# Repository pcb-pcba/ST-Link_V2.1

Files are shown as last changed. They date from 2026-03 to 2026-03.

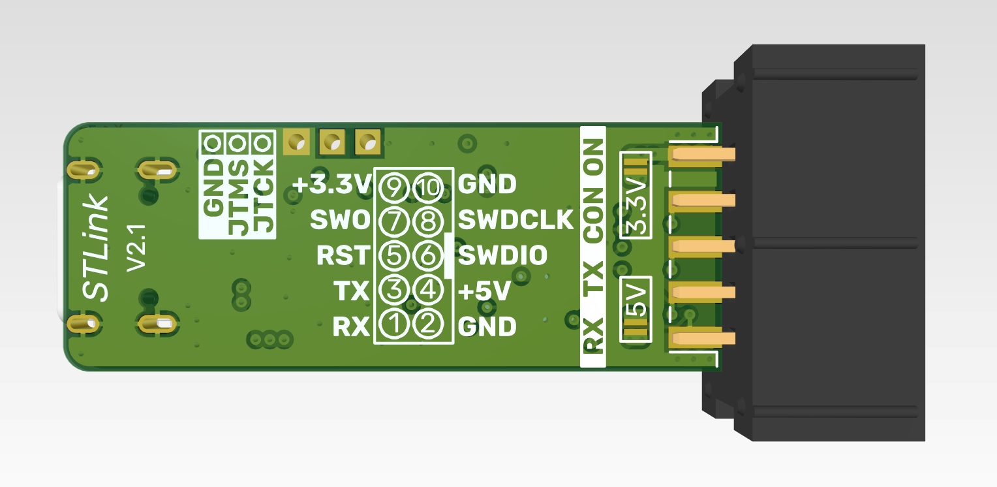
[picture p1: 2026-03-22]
Project/2.jpg

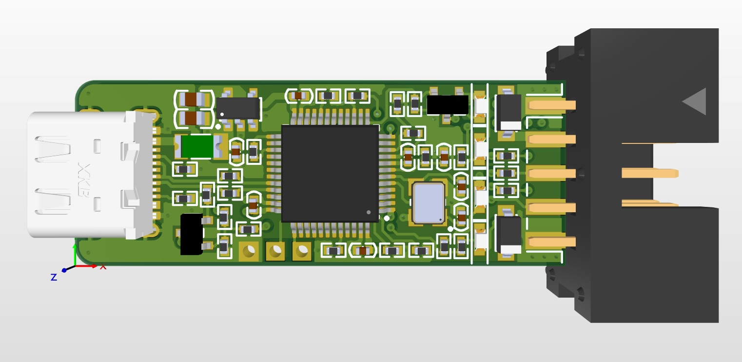
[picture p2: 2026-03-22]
Project/1.jpg

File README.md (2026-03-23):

# ST-Link V2.1

<p align="center">
  
</p>
<p align="center">
  
</p>

Small version of ST-Link v2.1 (37mm x 14mm board)<br><br>
**Features**
  - SWD (Serial Wire Debug) - standard pins used for external targets include SWDIO, SWCLK, GND, and sometimes NRST.
  - Virtual COM Port (VCP)
  - USB Power Management: Supports requesting more than 100 mA from the host PC to power the application board.
  - SWO Support: Includes a Serial Wire Output (SWO) pin for real-time trace debugging, which is often missing on common "dongle" clones of the V2.

`Draftsman_STLinkV2_1_rev1_0.pdf` - Some useful drawings

`Schematic_STLinkV2_1_rev1_0.pdf` - Schematic

`Project/` - Project files

`Gerber/STLinkV2_1_rev1_0.zip` - Gerber files

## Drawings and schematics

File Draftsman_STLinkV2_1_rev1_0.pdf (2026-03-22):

# ST-Link V2.1 V. 1.0

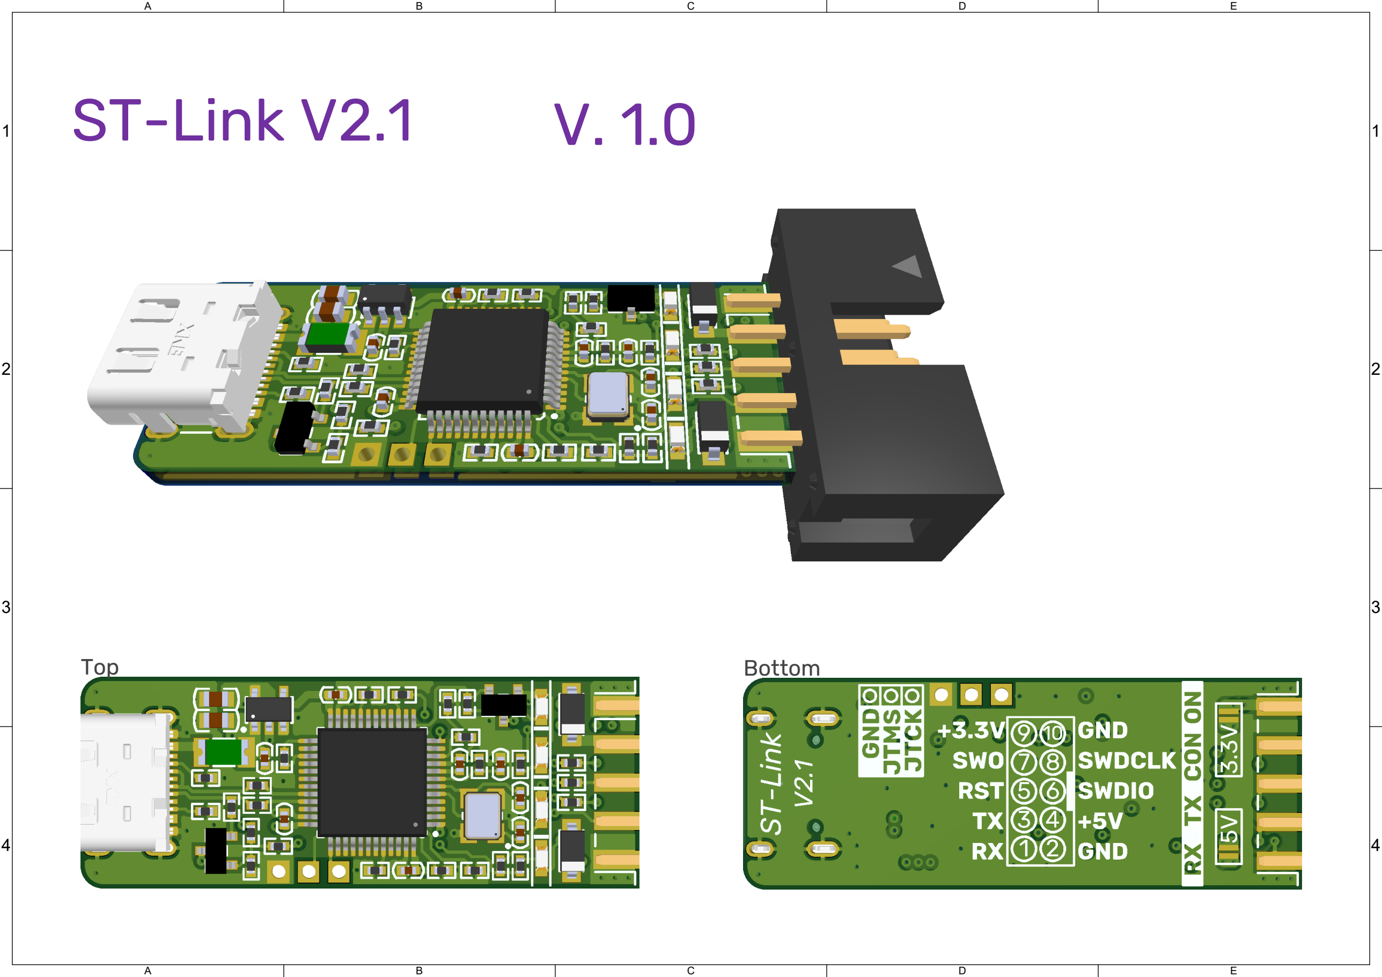
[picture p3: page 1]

A

B

C

D

E

1 | 1
2 | 2
3 | 3
4 | 4
Top | Bottom

## F1Q²

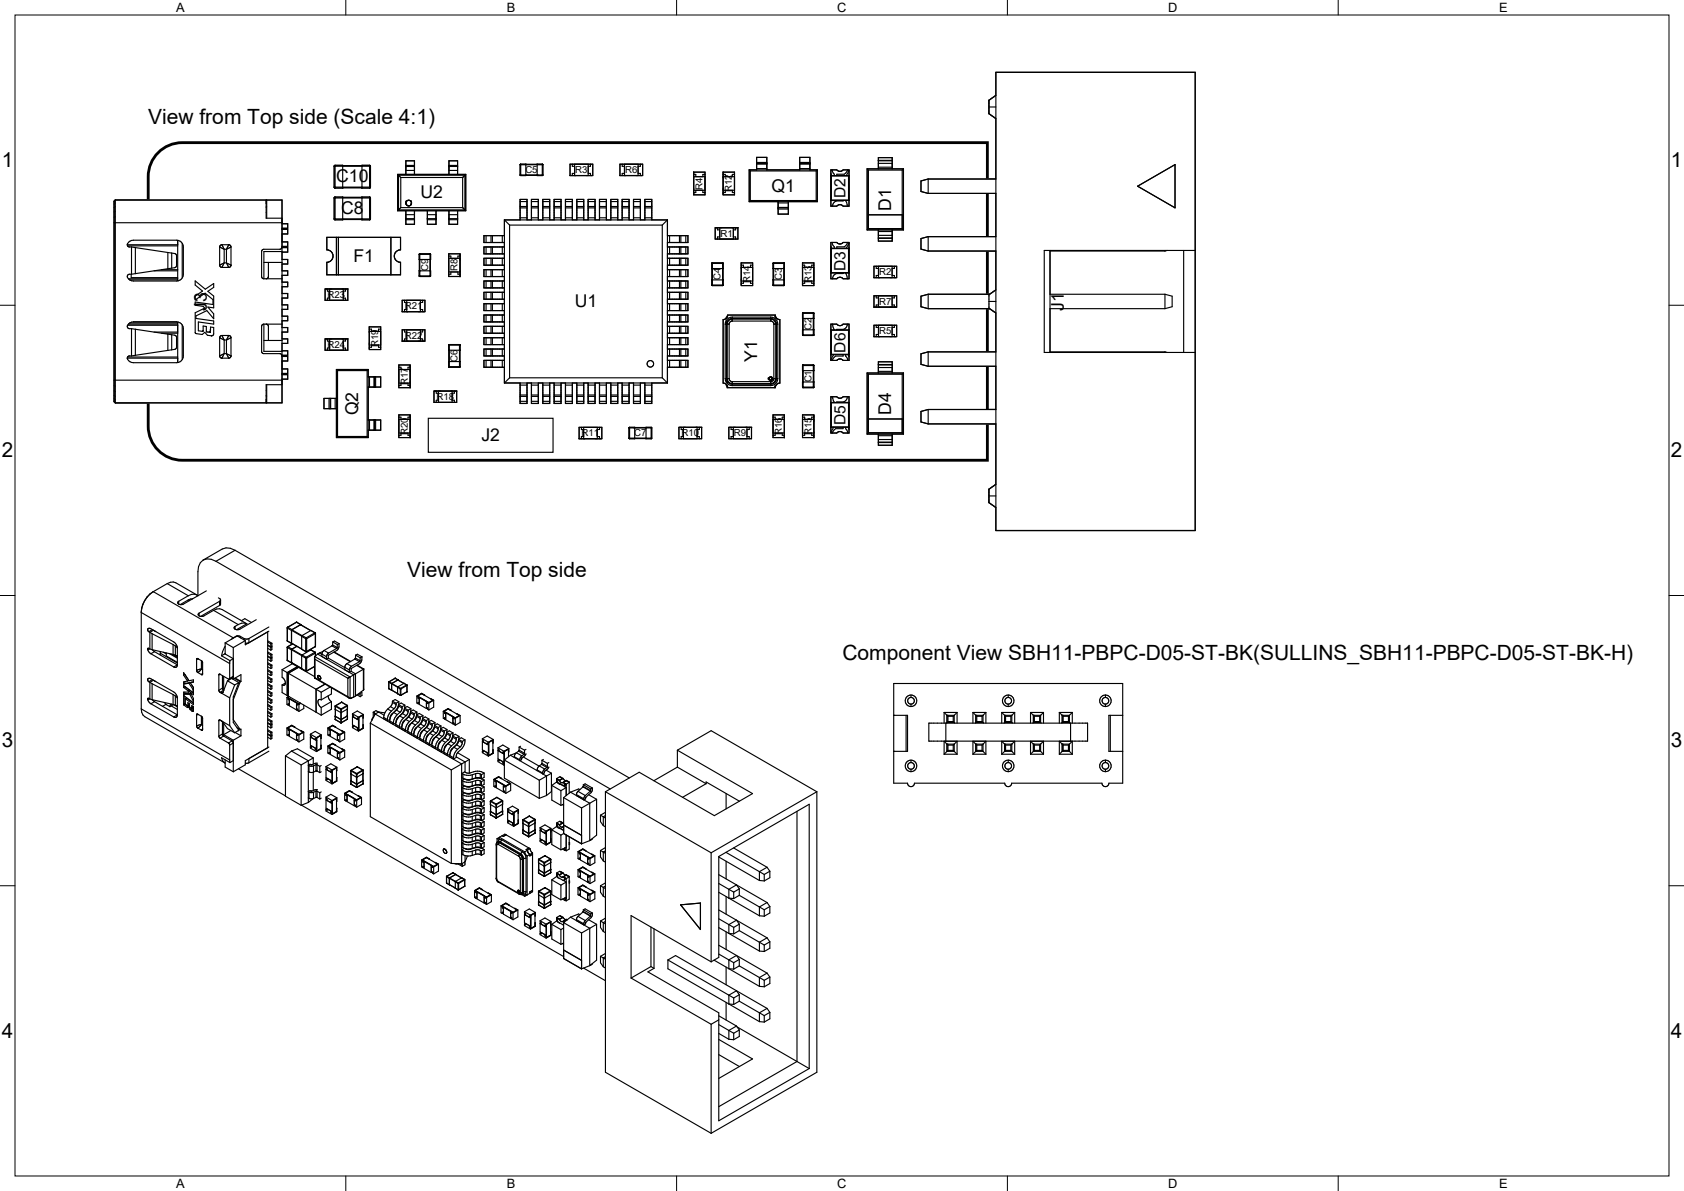
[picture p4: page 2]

View from Top side (Scale 4:1)

View from Top side

Component View SBH11-PBPC-D05-ST-BK(SULLINS_SBH11-PBPC-D05-ST-BK-H)

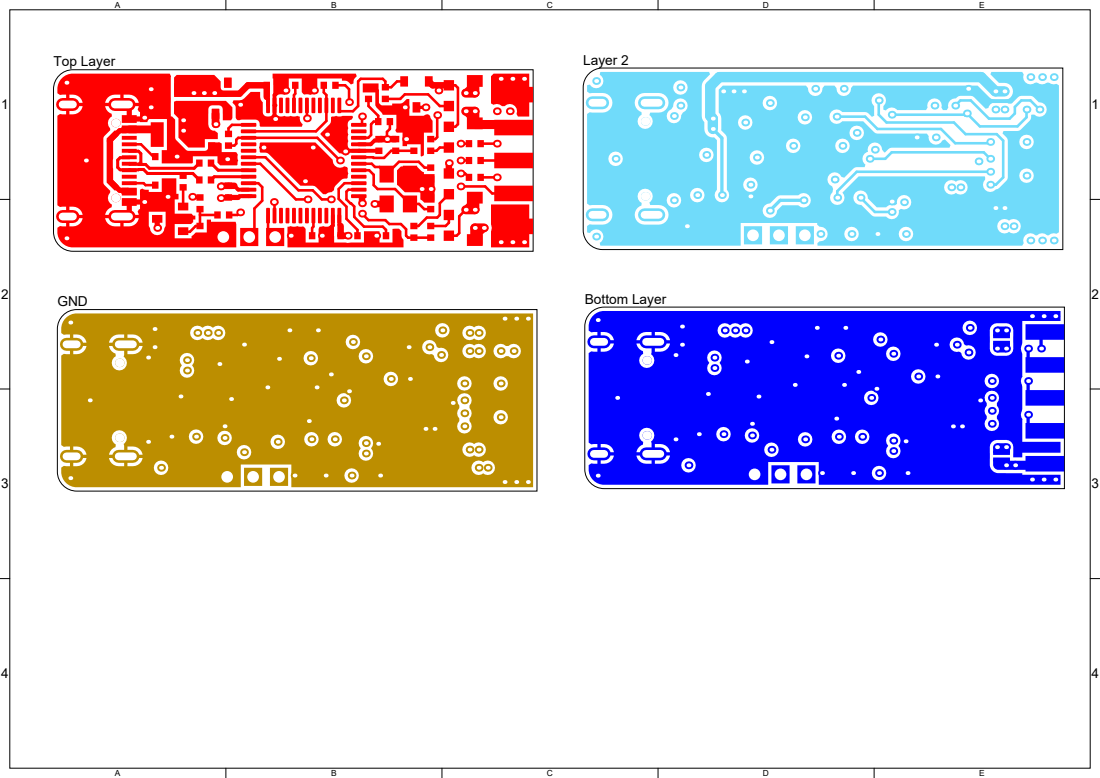
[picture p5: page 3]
Top Layer; GND; Layer 2; Bottom Layer

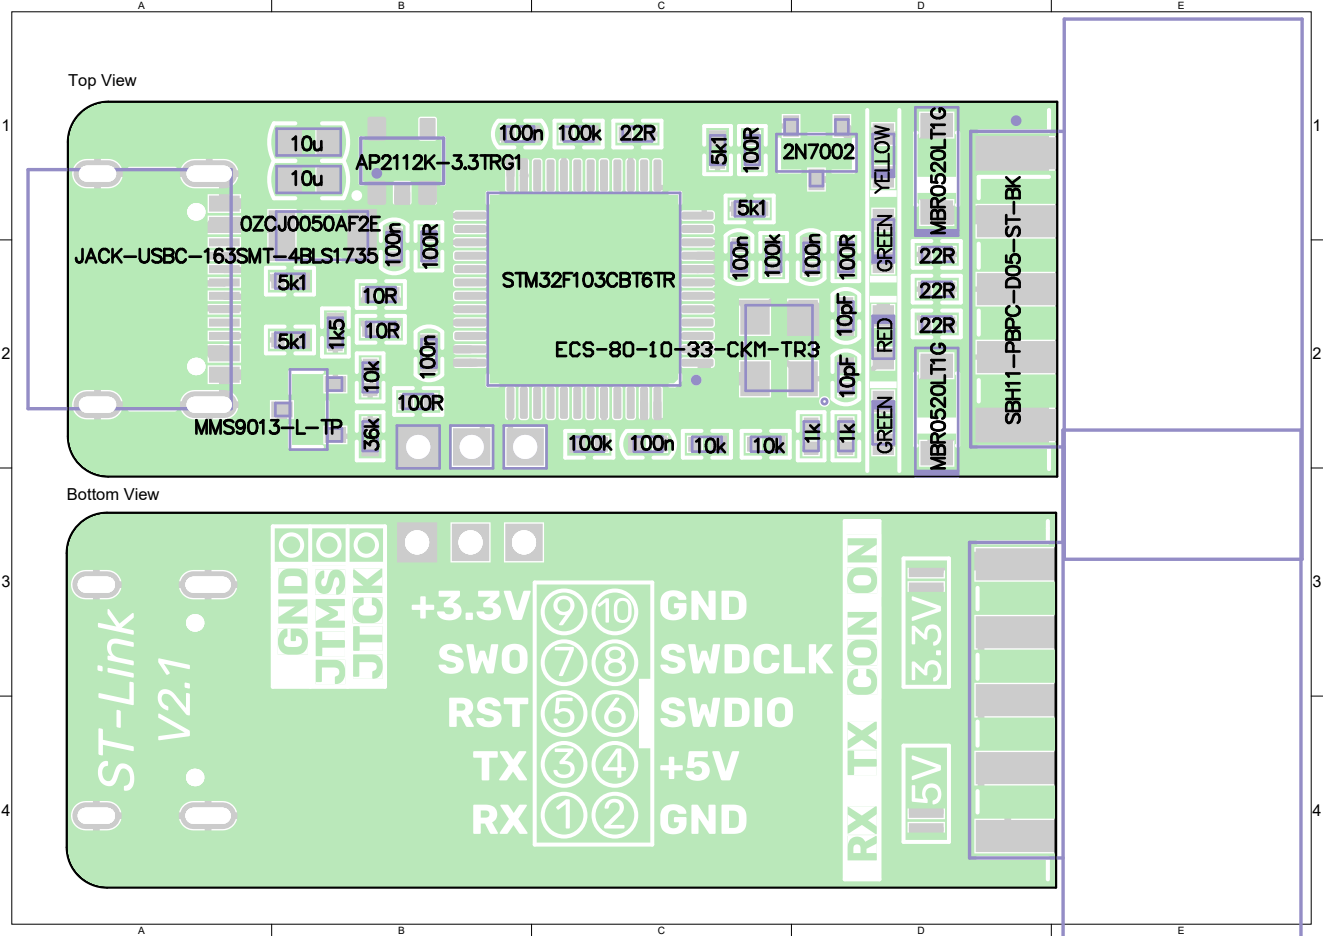
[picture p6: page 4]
Top View; Bottom View

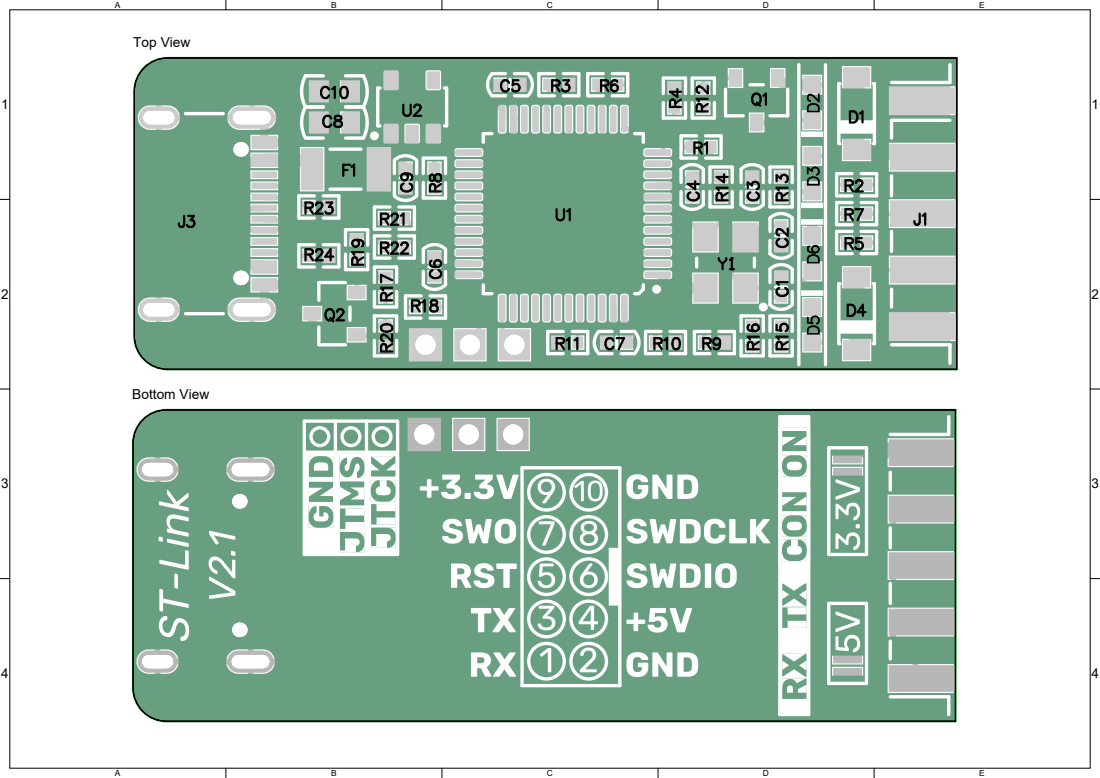
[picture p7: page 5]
Top View; Bottom View

1 | 1
2 | 2
3 | 3
4 | 4
Material | Layer | Thickness Dielectric Material Type | Gerber
| Top Overlay | | Legend | GTO
Surface Material Top Solder | 0.01mm | Solder Resist | Solder Mask GTS
Copper | Top Layer | 0.04mm | Signal | GTL
Prepreg | 0.21mm | PP-006 | Dielectric
CF-004 | GND | 0.02mm | Signal | G1
1.06mm | FR-4 | Dielectric
CF-004 | Layer 2 | 0.02mm | Signal | G2
Prepreg | 0.21mm | PP-006 | Dielectric
Copper | Bottom Layer | 0.04mm | Signal | GBL
Surface Material Bottom Solder 0.01mm | Solder Resist | Solder Mask GBS
| Bottom Overlay | | Legend | GBO
Total thickness: 1.61mm

Layer Stack Legend

1 | 1
2 | 2
3 | 3
4 | 4
Line # | Designator | Comment | Quantity | Manufacturer Part Number 1 | Case/Package | Description
1 | C1, C2 | 10pF | 2 | GCM1555C1H100JA16D | 0402 | 50V 10pF C0G ±5% 0402 Multilayer Ceramic Capacitors MLCC - SMD/SMT ROHS
2 | C3, C4, C5, C6, C7, C9 | 100n | 6 | GCM155R71H104KE02D | 0402 | 50V 100nF X7R ±10% 0402 Multilayer Ceramic Capacitors MLCC - SMD/SMT ROHS
3 | C8, C10 | 10u | 2 | GRM188C81C106MA73D | 0603 | 10 µF ±20% 16V Ceramic Capacitor X6S 0603 (1608 Metric)
4 | D1, D4 | MBR0520LT1G | 2 | MBR0520LT1G | SOD-123-2 | Diode, Schottky Barrier, Vr 20V, If 0.5A, Pkg SOD-123, Vf 0.385V, Tj +125DEGC, Cs 5.5A
5 | D2 | YELLOW | 1 | 150060YS75003 | | Led, Yellow, 550Mcd, 595Nm Rohs Compliant: Yes
6 | D3, D5 | GREEN | 2 | 150060VS75003 | | Led, Bright Green, 100Mcd, 572Nm Rohs Compliant: Yes
7 | D6 | RED | 1 | 150060RS75003 | 0603 | SMT Mono-Color Chip LED Waterclear Advance WL-SMCW_0603_ADVANCE
8 | F1 | 0ZCJ0050AF2E | 1 | 0ZCJ0050AF2E | 1206 | Resettable Fuse, PPTC, 1206 (3216 Metric), 0ZCJ Series, 24 VDC, 500 mA, 1 A, 0.1 s
9 | J1 | SBH11-PBPC-D05-ST-BK | 1 | SBH11-PBPC-D05-ST-BK | | Conn Shrouded Header (4 Sides) HDR 10 POS 2.54mm Solder ST Top Entry Thru-Hole
10 | J3 | JACK-USBC-163SMT-4BLS1735 | 1 | JACK-USBC-163SMT-4BLS1735 | | Usb Type C Jack IPX7 SMT
11 | Q1 | 2N7002 | 1 | 2N7002H6327XTSA2 | SOT-23 | MOSFET N-CH 60V 300MA SOT23-3 N-Channel 60 V 300mA (Ta) 500mW (Ta) Surface Mount PG-SOT23
12 | Q2 | MMS9013-L-TP | 1 | MMS9013-L-TP | SOT-23 | Small Signal Bipolar Transistor, 0.5A I(C), 25V V(BR)CEO, 1-Element, NPN, Silicon
13 | R1, R4, R23, R24 | 5k1 | 4 | AC0402FR-135K1L | 0402 | Res Thick Film 0402 5.1K Ohm 1% 0.063W(1/16W) ±100ppm/°C Pad SMD T/R Automotive AEC-Q200
14 | R2, R5, R6, R7 | 22R | 4 | AC0402FR-7W22RL | 0402 | 125mW Thick Film Resistors ±100ppm/℃ ±1% 22Ω 0402 Chip Resistor - Surface Mount ROHS
15 | R3, R11, R14 | 100k | 3 | AC0402FR-7W100KL | 0402 | Res Thick Film 0402 100K Ohm 1% 0.125W(1/8W) ±100ppm/°C Pad SMD T/R Automotive AEC-Q200
16 | R8, R12, R13, R18 | 100R | 4 | AC0402FR-7W100RL | 0402 | Res Thick Film 0402 100 Ohm 1% 0.125W(1/8W) ±100ppm/ C Pad SMD T/R Automotive AEC-Q200
17 | R9, R10, R17 | 10k | 3 | AC0402FR-7W10KL | 0402 | Res Thick Film 0402 10K Ohm 1% 0.125W(1/8W) ±100ppm/ C Pad SMD Automotive T/R
18 | R15, R16 | 1k | 2 | AC0402FR-7W1KL | 0402 | Res Thick Film 0402 1K Ohm 1% 0.125W(1/8W) ±100ppm/C Pad SMD Automotive T/R
19 | R19 | 1k5 | 1 | AC0402FR-7W1K5L | 0402 | Fixed Resistor, Metal Glaze/thick Film, 0.125W, 1500ohm, 75V, 1% +/-Tol, 100ppm/Cel, Surface Mount, 0402
20 | R20 | 36k | 1 | AC0402FR-7W36KL | 0402 | Chip Resistor Automotive Grade Thick Film 0402 36kOhm 1% Paper T/R
21 | R21, R22 | 10R | 2 | AC0402FR-7W10RL | 0402 | Res Thick Film 0402 10 Ohm 1% 0.125W(1/8W) ±100ppm/C Pad SMD T/R Automotive AEC-Q200
22 | U1 | STM32F103CBT6TR | 1 | STM32F103CBT6TR | LQFP | MCU 32-bit STM32F1 ARM Cortex M3 RISC 128KB Flash 2.5V/3.3V 48-Pin LQFP T/R
23 | U2 | AP2112K-3.3TRG1 | 1 | AP2112K-3.3TRG1 | SOT-23-5 | AP2112 Series 0.6 A 3.3 V Fixed Output SMT LDO Linear Regulator - SOT23-5
24 | Y1 | ECS-80-10-33-CKM-TR3 | 1 | ECS-80-10-33-CKM-TR3 | 4-SMD (3.2x2.5) | CRYSTAL 8.0000MHZ 10PF SMD

Bill Of Materials

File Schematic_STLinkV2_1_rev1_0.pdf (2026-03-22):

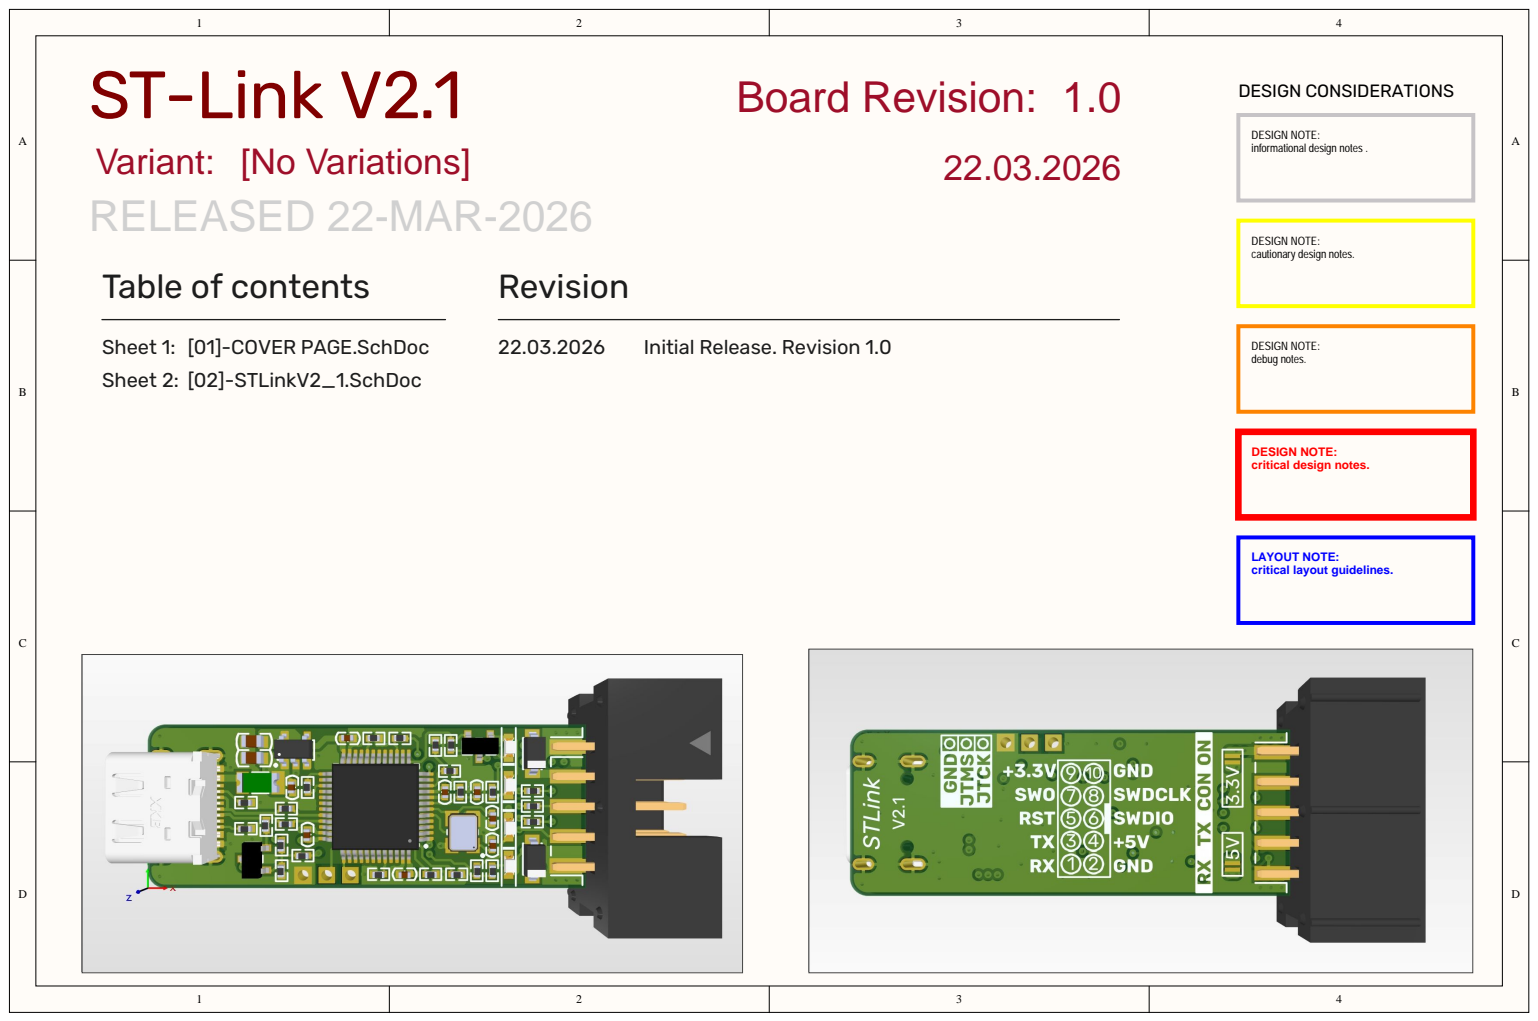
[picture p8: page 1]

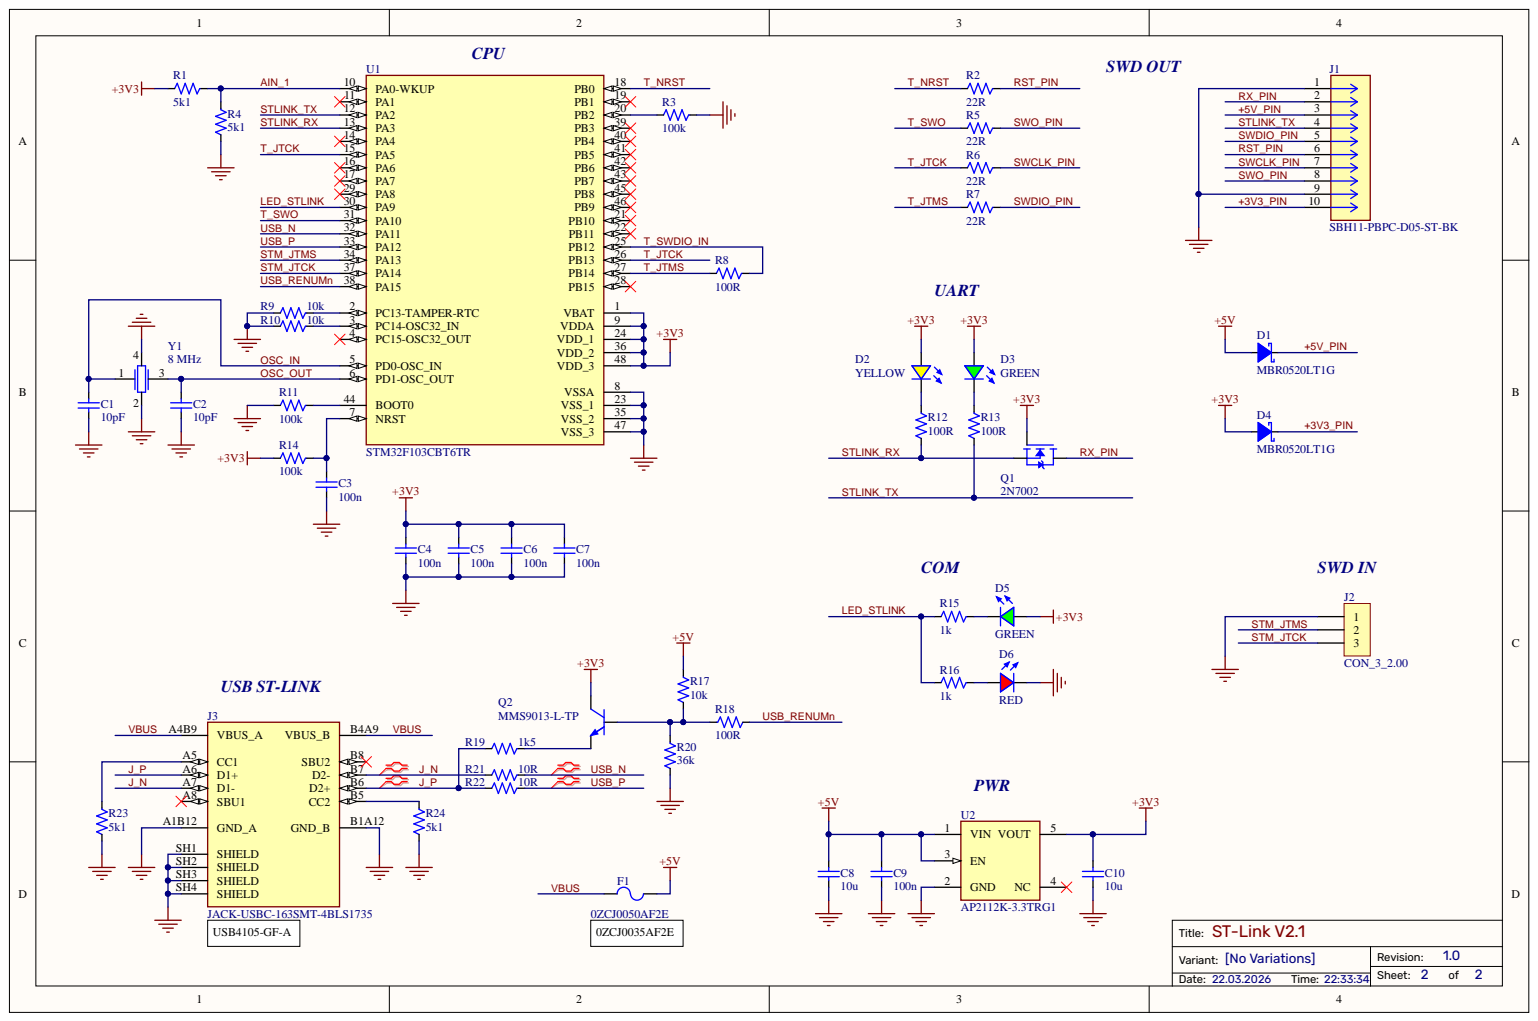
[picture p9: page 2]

SHIELD SH2
